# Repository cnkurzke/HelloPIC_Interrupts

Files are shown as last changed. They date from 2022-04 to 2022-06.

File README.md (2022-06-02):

# About

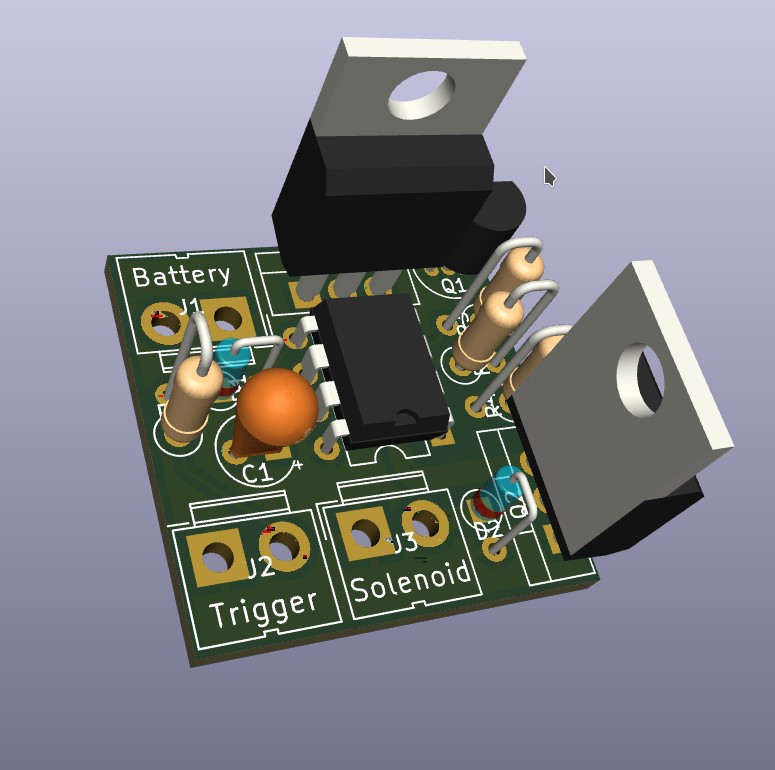
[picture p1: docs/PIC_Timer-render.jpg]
3D render PCB


This is part of my adventure of learning how to use PIC Microcontrollers in the real world.
If you want to learn more about what a PIC is, here are plenty of online resources. E.g. see here:

* https://en.wikipedia.org/wiki/PIC_microcontrollers
* https://www.microchip.com/en-us/products/microcontrollers-and-microprocessors
* https://pic-microcontroller.com/pic16f877-based-projects-pic-microcontroller-downloadable/

My intention is to document my learning journey, so others can hopefully find it useful on
their own research and learning path. I strongly encourage everyone who finds a mistake, 
be it an oversight or something out of date, *please file a bug, or even better, contribute a fix!*

## My Setup

I try to do this as cleaply as possible, so that it can be reproduced by everyone.

My primary workstation is a standard PC with Ubuntu (currently version 20.04), and I use the 
PicKit 3. If you intend to purchase a programmer, be aware that the PicKit 2 is no longer 
supported by the current (2022) generation of development tools.

As the software environmnet, I am not happy with the Microchip tools, but it is the quickest way to
get started.
In fact, I installed a Virtual Machine, and run the MPLab IDE inside the VM. But if you have a
more "traditional" operating system, you should be fine to run this on your standard computer.
Follow the steps here:
https://www.microchip.com/en-us/tools-resources/develop/mplab-x-ide

# What Does It Do

I started with a very simple problem. For a car I'm currently restoring, I needed something
to control the "Transmission Reverse Lock-Out". For a commercial device, look at 
https://shiftsst.com/tremec-6-speed-reverse-lockout-control-module.html

What's relevant for this level of detail:
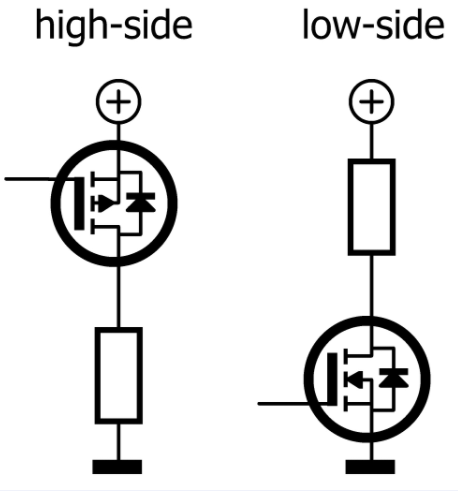
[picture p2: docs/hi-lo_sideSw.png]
Low-side vs. high-side
      

*  The goal is to drive an automotive grade 12 volt Solenoid which is wired to the car in a 
   "High-Side Switch" configuration.
   What this means:
   *  The module we build will have to be able to deliver high current, and it is an 
      "inductive load".
      Therefore I chose a beefy MOSFET to drive the signal to the transmission.
      
   *  The solenoid is permanently connected to "ground", and we have to close a switch to 12V to
      activate the solenoid and unlock the reverse gear. This means we have a 
      P-Channel MOSFET in "High Side Switching" configuration.
      For an example see here: https://www.elektormagazine.com/news/high-side-low-side-switching

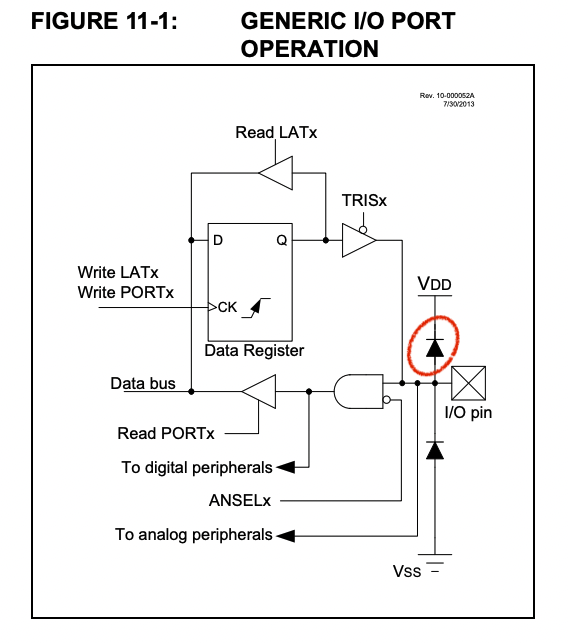
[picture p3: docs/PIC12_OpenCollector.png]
Open Collector with Clamping Diode
    * 
      The P-Channel MOSFET needs to be driven by a 12V Gate voltage, annd can unfortunately not
      be driven by the PIC output pin. Even though the Datasheet mentions that PIC outputs are
      able to work as "open Collector" - this is only thue for voltages within the operating
      voltage level. The circeled Diode in the diagram shows that the PIC has internal 
      clamping Diodes for protection.
      
*  The logic implemented by this device is to:
  *  Whenever the vehicle is turned on: Activate the solenoid for 30 seconds 
  *  When the driver pushes a trigger buttom: Activate the solenoid for 30 seconds 

This is a fairly simple timer circuit.

# Hardware Choices

After a bit of research, I decided the 8-pin PIC 12F1572 is more than capable.
It has 6 GPIOs, and holds 2KB memory.
See the datasheet here: https://www.microchip.com/en-us/product/PIC12F1572

For the MOSFET I decided to use the: https://www.sparkfun.com/datasheets/Components/General/FQP27P06.pdf
It can easily drive 20+ Amp, and most important, it has an integrated "fly back diode" to handle switching the inductive load.

Here's an early sketch of a circuit: 

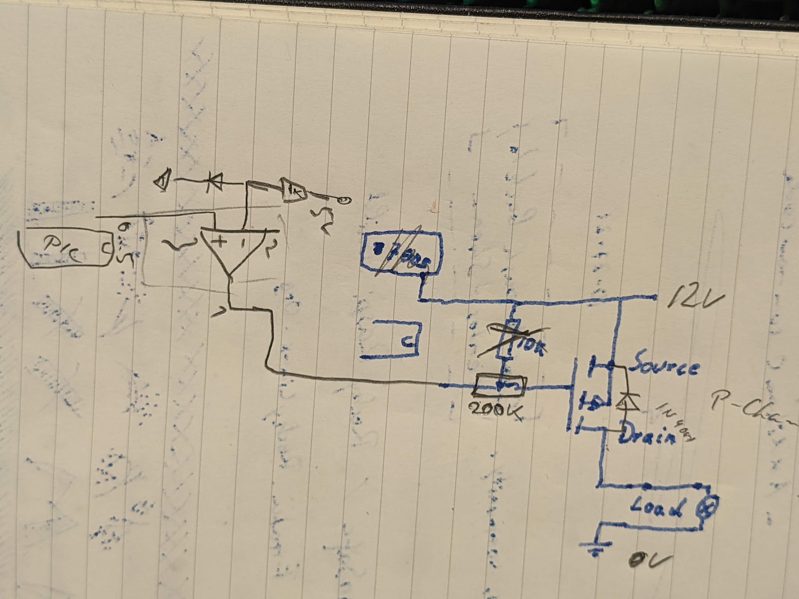
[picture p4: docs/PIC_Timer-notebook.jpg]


It became apparent rather quickly that the biggest challenge would be, how to drive the 12V MOSFET from the 5V PIC output.

## MOSFET Drriver

It turns out that the PIC output pins, even though they are "Open Collector" capable, they are protected by a diode, which prevents to pull-up to 12V.

I looked at various MOSFET Drivers, but they are really not needed, for the low (basically DC) switching  freqencies.
In this case, a simple NPN BJT in Open Collector mode is suficcient.

## Prototype

After a bit of breadboarding, I had the first version up and running rather quickly. 

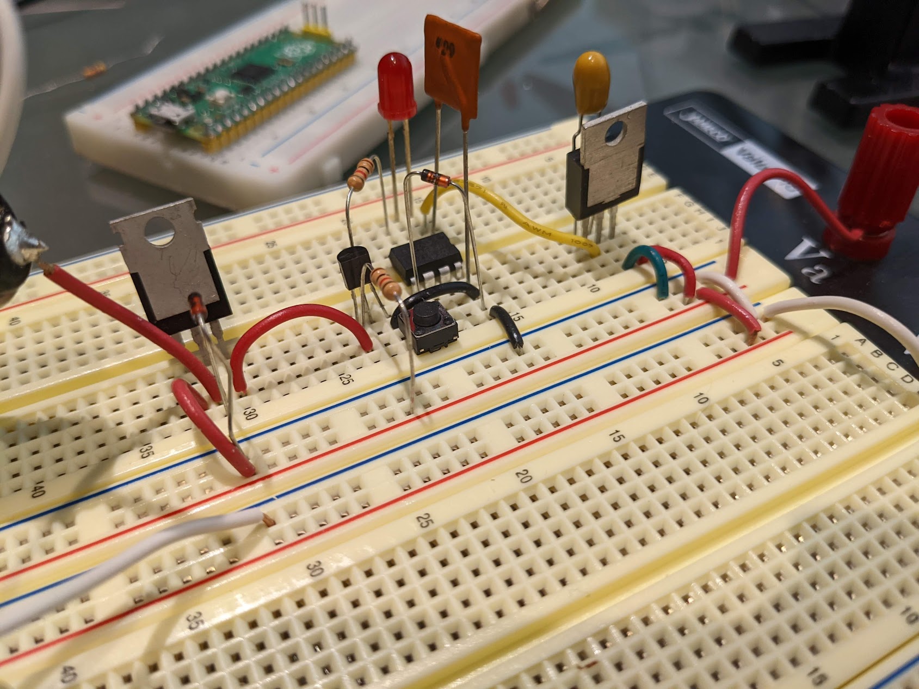
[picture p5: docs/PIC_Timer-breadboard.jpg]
Breadboard with components


# KiCAD Schematics

I decided to create "REAL" circuit boards. After a bit of research, the free software "KiCAD" cauught my interest. It's everything  I need, and way, way more!
See: https://www.kicad.org/

After some trial and error and watching tutorials like: https://www.youtube.com/watch?v=ia2n7P3Csac

I created this schematic:
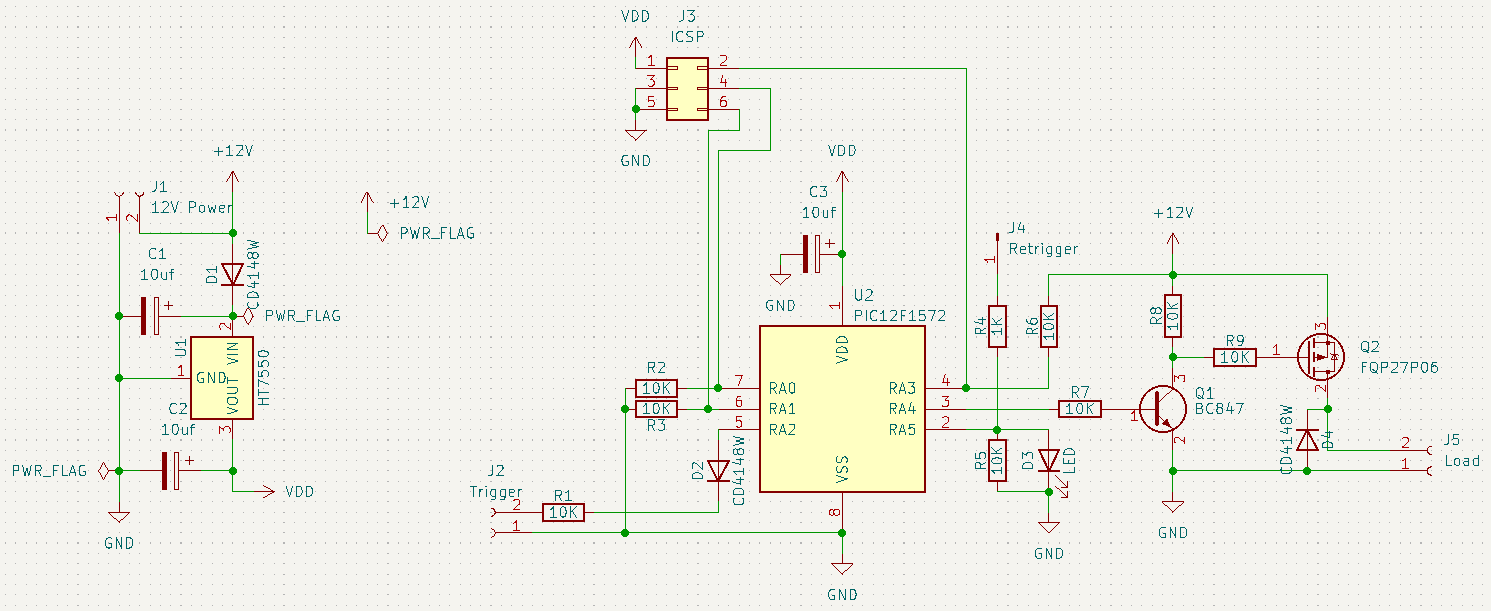
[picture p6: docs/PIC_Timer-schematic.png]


The source for this is here: https://github.com/cnkurzke/HelloPIC_Interrupts/tree/master/schematics

# PCB Layout

With the help of KiCAD, i turned this schematic into a circuit board, and Gerber files: 
https://github.com/cnkurzke/HelloPIC_Interrupts/tree/master/schematics/KiCAD_project/PIC_Timer/gerbers

The Gerber files describe the PCB and are used to manufacture the final boards:
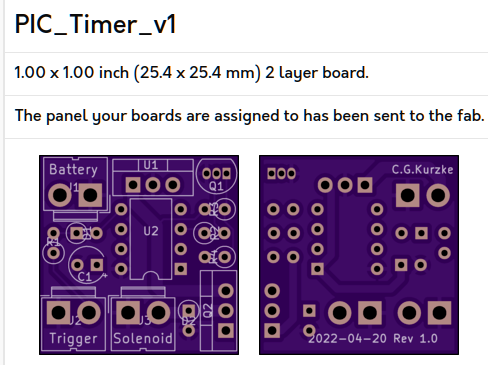
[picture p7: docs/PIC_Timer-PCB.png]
Printed Circuit Board


... stay tuned, the boards will arrive in 5 days

To be continued

# SOFTWARE 

## HelloPIC_Interrupts
Sample code for the PIC 12F1572 interrupt handling.

For a very basic introduction about Interrupts on PIC see:
https://picguides.com/beginner/interrupts.php

The Interrupt handler gets registered in main.c, with     
`IOCAF2_SetInterruptHandler(IOCAF2_CGK_InterruptHandler);`

The ISR (`IOCAF2_CGK_InterruptHandler()`) is called everytime the RA2 is pulled to LOW.

More in detail information about De-Bouncing Switches: 
http://www.ganssle.com/debouncing-pt2.htm

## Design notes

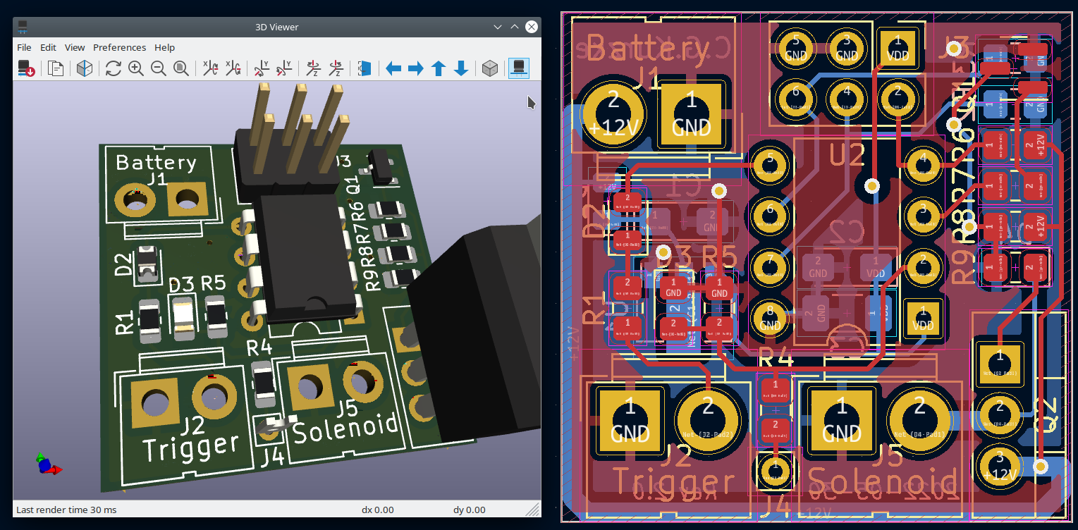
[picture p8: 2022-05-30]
docs/PIC_Timer-PCB-SMD-3D.png

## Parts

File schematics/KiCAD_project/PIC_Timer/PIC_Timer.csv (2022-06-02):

Source: | /home/cgk/MPLABXProjects/HelloInterrupt.X/schematics/KiCAD_project/PIC_Timer/PIC_Timer.kicad_sch
Date: | Mon 30 May 2022 12:20:11 AM PDT
Tool: | Eeschema 6.0.5-a6ca702e91~116~ubuntu20.04.1
Generator: | /usr/share/kicad/plugins/bom_csv_grouped_by_value_with_fp.py
Component Count: | 25
Ref | Qnty | Value | Cmp name | Footprint | Description | Vendor
C1, C2, | 2 | 10uf | C_Polarized | Capacitor_Tantalum_SMD:CP_EIA-3216-10_Kemet-I_Pad1.58x1.35mm_HandSolder | Polarized capacitor
C3, | 1 | 10uf | C_Polarized | Capacitor_SMD:C_1206_3216Metric_Pad1.33x1.80mm_HandSolder | Polarized capacitor
D1, D2, D4, | 3 | CD4148W | CD4148W | Diode_SMD:D_0805_2012Metric | 75V 0.15A Switching Diode, 0805
D3, | 1 | LED | LED | LED_SMD:LED_0805_2012Metric_Pad1.15x1.40mm_HandSolder | Light emitting diode
J1, | 1 | 12V Power | Conn_01x02_Female | Connector:JWT_A3963_1x02_P3.96mm_Vertical | Generic connector, single row, 01x02, script generated (kicad-library-utils/schlib/autogen/connector/)
J2, | 1 | Trigger | Conn_01x02_Female | Connector:JWT_A3963_1x02_P3.96mm_Vertical | Generic connector, single row, 01x02, script generated (kicad-library-utils/schlib/autogen/connector/)
J3, | 1 | ICSP | Conn_02x03_Odd_Even | Connector_PinHeader_2.54mm:PinHeader_2x03_P2.54mm_Vertical | Generic connector, double row, 02x03, odd/even pin numbering scheme (row 1 odd numbers, row 2 even numbers), script generated (kicad-library-utils/schlib/autogen/connector/)
J4, | 1 | Retrigger | Conn_01x01_Male | Connector_Pin:Pin_D0.7mm_L6.5mm_W1.8mm_FlatFork | Generic connector, single row, 01x01, script generated (kicad-library-utils/schlib/autogen/connector/)
J5, | 1 | Load | Conn_01x02_Female | Connector:JWT_A3963_1x02_P3.96mm_Vertical | Generic connector, single row, 01x02, script generated (kicad-library-utils/schlib/autogen/connector/)
Q1, | 1 | BC847 | BC847 | Package_TO_SOT_SMD:SOT-23 | 0.1A Ic, 45V Vce, NPN Transistor, SOT-23
Q2, | 1 | FQP27P06 | FQP27P06 | Package_TO_SOT_THT:TO-220-3_Vertical | -27A Id, -60V Vds, QFET P-Channel MOSFET, TO-220
R1, R2, R3, R5, R6, R7, R8, R9, | 8 | 10K | R | Resistor_SMD:R_0805_2012Metric_Pad1.20x1.40mm_HandSolder | Resistor
R4, | 1 | 1K | R | Resistor_SMD:R_0805_2012Metric_Pad1.20x1.40mm_HandSolder | Resistor
U1, | 1 | HT7550 | HT75xx-1-SOT89 | Package_TO_SOT_SMD:SOT-89-3 | 100mA Low Dropout Voltage Regulator, Fixed Output, SOT89
U2, | 1 | PIC12F1572 | PIC12F1501-IP | Package_DIP:DIP-8_W7.62mm | 1024W FLASH, 64B SRAM, PDIP8

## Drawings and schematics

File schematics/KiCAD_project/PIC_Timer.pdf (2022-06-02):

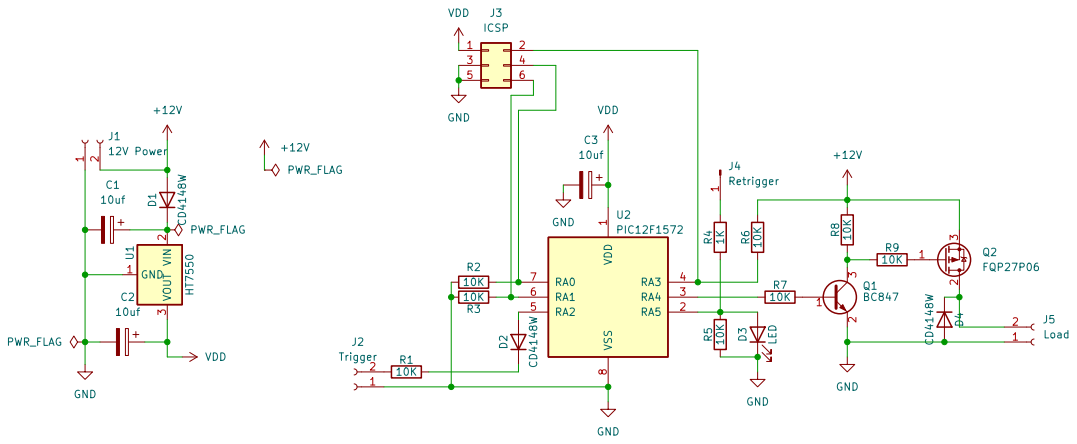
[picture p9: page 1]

Added retrigger and dedbug LED
Use SMD to accomodate better layout
File: PIC_Timer.kicad_sch Sheet: / Slipstream Systems, LLC

Id: 1/1 Title: Delay / Retrigger - Control Power MOSFET

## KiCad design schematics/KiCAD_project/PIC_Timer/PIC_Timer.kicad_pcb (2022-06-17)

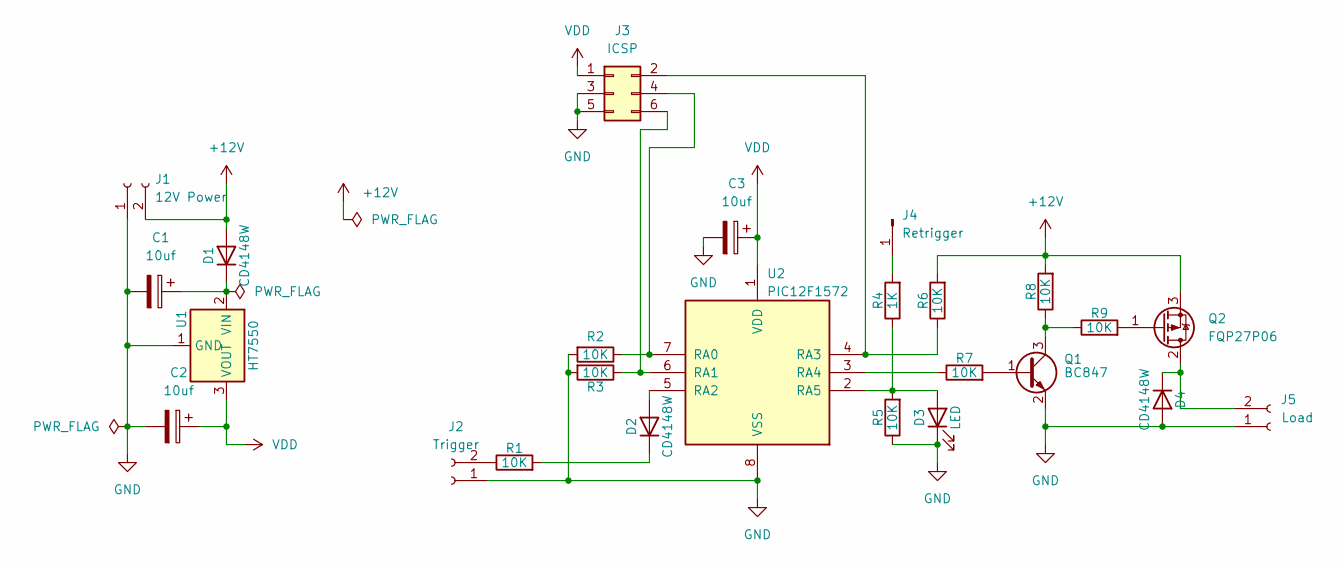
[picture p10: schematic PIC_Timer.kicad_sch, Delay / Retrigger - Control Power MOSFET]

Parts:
C1, C2: 10uf; CP_EIA-3216-10_Kemet-I_Pad1.58x1.35mm_HandSolder
C3: 10uf; C_1206_3216Metric_Pad1.33x1.80mm_HandSolder
D1, D2, D4: CD4148W; D_0805_2012Metric
D3: LED; LED_0805_2012Metric_Pad1.15x1.40mm_HandSolder
J1: 12V Power; JWT_A3963_1x02_P3.96mm_Vertical
J2: Trigger; JWT_A3963_1x02_P3.96mm_Vertical
J3: ICSP; PinHeader_2x03_P2.54mm_Vertical
J4: Retrigger; Pin_D0.7mm_L6.5mm_W1.8mm_FlatFork
J5: Load; JWT_A3963_1x02_P3.96mm_Vertical
Q1: BC847; SOT-23
Q2: FQP27P06; TO-220-3_Vertical
R1, R2, R3, R5, R6, R7, R8, R9: 10K; R_0805_2012Metric_Pad1.20x1.40mm_HandSolder
R4: 1K; R_0805_2012Metric_Pad1.20x1.40mm_HandSolder
U1: HT7550; SOT-89-3
U2: PIC12F1572; DIP-8_W7.62mm

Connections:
+12V: D1.2 (A), J1.2, Q2.3 (S), R6.2, R8.2
GND: C1.2, C2.2, C3.2, D3.1 (K), D4.2 (A), J1.1, J2.1, J3.3, J3.5, J5.1, Q1.2 (E), R2.2, R3.2, R5.1, U1.1 (GND), U2.8 (VSS)
unnamed: C1.1, D1.1 (K), U1.2 (VIN)
unnamed: D2.1 (K), R1.2
unnamed: D2.2 (A), U2.5 (RA2)
unnamed: D3.2 (A), R4.1, R5.2, U2.2 (RA5)
unnamed: D4.1 (K), J5.2, Q2.2 (D)
unnamed: J2.2, R1.1
unnamed: J3.2, R6.1, U2.4 (RA3)
unnamed: J3.4, R2.1, U2.7 (RA0)
unnamed: J3.6, R3.1, U2.6 (RA1)
unnamed: J4.1, R4.2
unnamed: Q1.1 (B), R7.2
unnamed: Q1.3 (C), R8.1, R9.1
unnamed: Q2.1 (G), R9.2
unnamed: R7.1, U2.3 (RA4)
VDD: C2.1, C3.1, J3.1, U1.3 (VOUT), U2.1 (VDD)

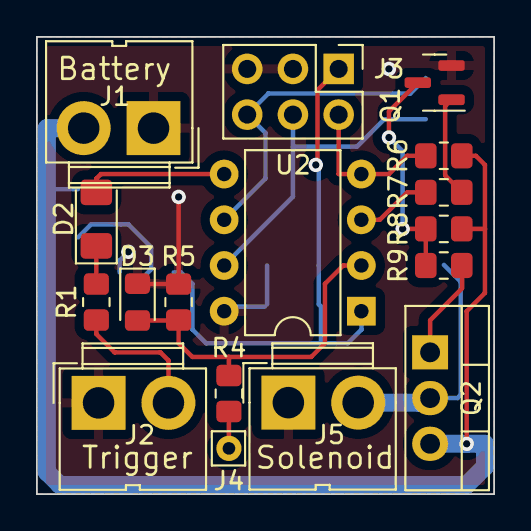
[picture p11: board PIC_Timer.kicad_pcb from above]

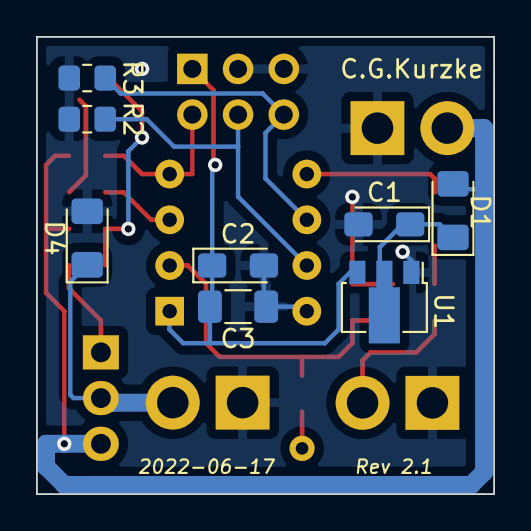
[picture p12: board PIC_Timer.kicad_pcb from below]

Board: 2 copper layers, 25.4 x 25.4 mm, 25 parts (8 on the bottom side), 17 nets.

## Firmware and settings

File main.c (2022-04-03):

/**
  Generated Main Source File

  Company:
    Microchip Technology Inc.

  File Name:
    main.c

  Summary:
    This is the main file generated using PIC10 / PIC12 / PIC16 / PIC18 MCUs

  Description:
    This header file provides implementations for driver APIs for all modules selected in the GUI.
    Generation Information :
        Product Revision  :  PIC10 / PIC12 / PIC16 / PIC18 MCUs - 1.81.7
        Device            :  PIC12F1572
        Driver Version    :  2.00
*/

/*
    (c) 2018 Microchip Technology Inc. and its subsidiaries. 
    
    Subject to your compliance with these terms, you may use Microchip software and any 
    derivatives exclusively with Microchip products. It is your responsibility to comply with third party 
    license terms applicable to your use of third party software (including open source software) that 
    may accompany Microchip software.
    
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
    IN NO EVENT WILL MICROCHIP BE LIABLE FOR ANY INDIRECT, SPECIAL, PUNITIVE, 
    INCIDENTAL OR CONSEQUENTIAL LOSS, DAMAGE, COST OR EXPENSE OF ANY KIND 
    WHATSOEVER RELATED TO THE SOFTWARE, HOWEVER CAUSED, EVEN IF MICROCHIP 
    HAS BEEN ADVISED OF THE POSSIBILITY OR THE DAMAGES ARE FORESEEABLE. TO 
    THE FULLEST EXTENT ALLOWED BY LAW, MICROCHIP'S TOTAL LIABILITY ON ALL 
    CLAIMS IN ANY WAY RELATED TO THIS SOFTWARE WILL NOT EXCEED THE AMOUNT 
    OF FEES, IF ANY, THAT YOU HAVE PAID DIRECTLY TO MICROCHIP FOR THIS 
    SOFTWARE.
*/

#include "mcc_generated_files/mcc.h"

/*
                         Main application
 */


#define LOCKOUT_TIME 10         // time in seconds
#define LOCKOUT_GRANULARITY 100 // granularity in millisec
volatile int32_t g_lockoutTimer = LOCKOUT_TIME * 1000 / LOCKOUT_GRANULARITY;

void IOCAF2_CGK_InterruptHandler(void){
    // IO_RA4_Toggle();
    g_lockoutTimer = LOCKOUT_TIME * 1000 / LOCKOUT_GRANULARITY;
}


void main(void)
{
    // initialize the device
    SYSTEM_Initialize();

    // When using interrupts, you need to set the Global and Peripheral Interrupt Enable bits
    // Use the following macros to:

    // Enable the Global Interrupts
    INTERRUPT_GlobalInterruptEnable();

    // Enable the Peripheral Interrupts
    INTERRUPT_PeripheralInterruptEnable();

    // Disable the Global Interrupts
    //INTERRUPT_GlobalInterruptDisable();

    // Disable the Peripheral Interrupts
    //INTERRUPT_PeripheralInterruptDisable();

    // register Interrupt Handler Function 
    IOCAF2_SetInterruptHandler(IOCAF2_CGK_InterruptHandler);
   
    IO_RA5_SetHigh();
    IO_RA4_SetHigh();
    
    while (1)
    {
        // Add your application code
        //IO_RA4_Toggle();
        IO_RA5_Toggle();
        
        if (g_lockoutTimer > 0) {
            g_lockoutTimer--;
            IO_RA4_SetHigh();
        } else {
            IO_RA4_SetLow();
        }
           
        
        __delay_ms(LOCKOUT_GRANULARITY);
        
    }
}
/**
 End of File
*/

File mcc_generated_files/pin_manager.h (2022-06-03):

/**
  @Generated Pin Manager Header File

  @Company:
    Microchip Technology Inc.

  @File Name:
    pin_manager.h

  @Summary:
    This is the Pin Manager file generated using PIC10 / PIC12 / PIC16 / PIC18 MCUs

  @Description
    This header file provides APIs for driver for .
    Generation Information :
        Product Revision  :  PIC10 / PIC12 / PIC16 / PIC18 MCUs - 1.81.7
        Device            :  PIC12F1572
        Driver Version    :  2.11
    The generated drivers are tested against the following:
        Compiler          :  XC8 2.31 and above
        MPLAB 	          :  MPLAB X 5.45	
*/

/*
    (c) 2018 Microchip Technology Inc. and its subsidiaries. 
    
    Subject to your compliance with these terms, you may use Microchip software and any 
    derivatives exclusively with Microchip products. It is your responsibility to comply with third party 
    license terms applicable to your use of third party software (including open source software) that 
    may accompany Microchip software.
    
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
    IN NO EVENT WILL MICROCHIP BE LIABLE FOR ANY INDIRECT, SPECIAL, PUNITIVE, 
    INCIDENTAL OR CONSEQUENTIAL LOSS, DAMAGE, COST OR EXPENSE OF ANY KIND 
    WHATSOEVER RELATED TO THE SOFTWARE, HOWEVER CAUSED, EVEN IF MICROCHIP 
    HAS BEEN ADVISED OF THE POSSIBILITY OR THE DAMAGES ARE FORESEEABLE. TO 
    THE FULLEST EXTENT ALLOWED BY LAW, MICROCHIP'S TOTAL LIABILITY ON ALL 
    CLAIMS IN ANY WAY RELATED TO THIS SOFTWARE WILL NOT EXCEED THE AMOUNT 
    OF FEES, IF ANY, THAT YOU HAVE PAID DIRECTLY TO MICROCHIP FOR THIS 
    SOFTWARE.
*/

#ifndef PIN_MANAGER_H
#define PIN_MANAGER_H

/**
  Section: Included Files
*/

#include <xc.h>

#define INPUT   1
#define OUTPUT  0

#define HIGH    1
#define LOW     0

#define ANALOG      1
#define DIGITAL     0

#define PULL_UP_ENABLED      1
#define PULL_UP_DISABLED     0

// get/set IO_RA0 aliases
#define IO_RA0_TRIS                 TRISAbits.TRISA0
#define IO_RA0_LAT                  LATAbits.LATA0
#define IO_RA0_PORT                 PORTAbits.RA0
#define IO_RA0_WPU                  WPUAbits.WPUA0
#define IO_RA0_OD                   ODCONAbits.ODA0
#define IO_RA0_ANS                  ANSELAbits.ANSA0
#define IO_RA0_SetHigh()            do { LATAbits.LATA0 = 1; } while(0)
#define IO_RA0_SetLow()             do { LATAbits.LATA0 = 0; } while(0)
#define IO_RA0_Toggle()             do { LATAbits.LATA0 = ~LATAbits.LATA0; } while(0)
#define IO_RA0_GetValue()           PORTAbits.RA0
#define IO_RA0_SetDigitalInput()    do { TRISAbits.TRISA0 = 1; } while(0)
#define IO_RA0_SetDigitalOutput()   do { TRISAbits.TRISA0 = 0; } while(0)
#define IO_RA0_SetPullup()          do { WPUAbits.WPUA0 = 1; } while(0)
#define IO_RA0_ResetPullup()        do { WPUAbits.WPUA0 = 0; } while(0)
#define IO_RA0_SetPushPull()        do { ODCONAbits.ODA0 = 0; } while(0)
#define IO_RA0_SetOpenDrain()       do { ODCONAbits.ODA0 = 1; } while(0)
#define IO_RA0_SetAnalogMode()      do { ANSELAbits.ANSA0 = 1; } while(0)
#define IO_RA0_SetDigitalMode()     do { ANSELAbits.ANSA0 = 0; } while(0)

// get/set IO_RA1 aliases
#define IO_RA1_TRIS                 TRISAbits.TRISA1
#define IO_RA1_LAT                  LATAbits.LATA1
#define IO_RA1_PORT                 PORTAbits.RA1
#define IO_RA1_WPU                  WPUAbits.WPUA1
#define IO_RA1_OD                   ODCONAbits.ODA1
#define IO_RA1_ANS                  ANSELAbits.ANSA1
#define IO_RA1_SetHigh()            do { LATAbits.LATA1 = 1; } while(0)
#define IO_RA1_SetLow()             do { LATAbits.LATA1 = 0; } while(0)
#define IO_RA1_Toggle()             do { LATAbits.LATA1 = ~LATAbits.LATA1; } while(0)
#define IO_RA1_GetValue()           PORTAbits.RA1
#define IO_RA1_SetDigitalInput()    do { TRISAbits.TRISA1 = 1; } while(0)
#define IO_RA1_SetDigitalOutput()   do { TRISAbits.TRISA1 = 0; } while(0)
#define IO_RA1_SetPullup()          do { WPUAbits.WPUA1 = 1; } while(0)
#define IO_RA1_ResetPullup()        do { WPUAbits.WPUA1 = 0; } while(0)
#define IO_RA1_SetPushPull()        do { ODCONAbits.ODA1 = 0; } while(0)
#define IO_RA1_SetOpenDrain()       do { ODCONAbits.ODA1 = 1; } while(0)
#define IO_RA1_SetAnalogMode()      do { ANSELAbits.ANSA1 = 1; } while(0)
#define IO_RA1_SetDigitalMode()     do { ANSELAbits.ANSA1 = 0; } while(0)

// get/set IO_RA2 aliases
#define IO_RA2_TRIS                 TRISAbits.TRISA2
#define IO_RA2_LAT                  LATAbits.LATA2
#define IO_RA2_PORT                 PORTAbits.RA2
#define IO_RA2_WPU                  WPUAbits.WPUA2
#define IO_RA2_OD                   ODCONAbits.ODA2
#define IO_RA2_ANS                  ANSELAbits.ANSA2
#define IO_RA2_SetHigh()            do { LATAbits.LATA2 = 1; } while(0)
#define IO_RA2_SetLow()             do { LATAbits.LATA2 = 0; } while(0)
#define IO_RA2_Toggle()             do { LATAbits.LATA2 = ~LATAbits.LATA2; } while(0)
#define IO_RA2_GetValue()           PORTAbits.RA2
#define IO_RA2_SetDigitalInput()    do { TRISAbits.TRISA2 = 1; } while(0)
#define IO_RA2_SetDigitalOutput()   do { TRISAbits.TRISA2 = 0; } while(0)
#define IO_RA2_SetPullup()          do { WPUAbits.WPUA2 = 1; } while(0)
#define IO_RA2_ResetPullup()        do { WPUAbits.WPUA2 = 0; } while(0)
#define IO_RA2_SetPushPull()        do { ODCONAbits.ODA2 = 0; } while(0)
#define IO_RA2_SetOpenDrain()       do { ODCONAbits.ODA2 = 1; } while(0)
#define IO_RA2_SetAnalogMode()      do { ANSELAbits.ANSA2 = 1; } while(0)
#define IO_RA2_SetDigitalMode()     do { ANSELAbits.ANSA2 = 0; } while(0)

// get/set IO_RA4 aliases
#define IO_RA4_TRIS                 TRISAbits.TRISA4
#define IO_RA4_LAT                  LATAbits.LATA4
#define IO_RA4_PORT                 PORTAbits.RA4
#define IO_RA4_WPU                  WPUAbits.WPUA4
#define IO_RA4_OD                   ODCONAbits.ODA4
#define IO_RA4_ANS                  ANSELAbits.ANSA4
#define IO_RA4_SetHigh()            do { LATAbits.LATA4 = 1; } while(0)
#define IO_RA4_SetLow()             do { LATAbits.LATA4 = 0; } while(0)
#define IO_RA4_Toggle()             do { LATAbits.LATA4 = ~LATAbits.LATA4; } while(0)
#define IO_RA4_GetValue()           PORTAbits.RA4
#define IO_RA4_SetDigitalInput()    do { TRISAbits.TRISA4 = 1; } while(0)
#define IO_RA4_SetDigitalOutput()   do { TRISAbits.TRISA4 = 0; } while(0)
#define IO_RA4_SetPullup()          do { WPUAbits.WPUA4 = 1; } while(0)
#define IO_RA4_ResetPullup()        do { WPUAbits.WPUA4 = 0; } while(0)
#define IO_RA4_SetPushPull()        do { ODCONAbits.ODA4 = 0; } while(0)
#define IO_RA4_SetOpenDrain()       do { ODCONAbits.ODA4 = 1; } while(0)
#define IO_RA4_SetAnalogMode()      do { ANSELAbits.ANSA4 = 1; } while(0)
#define IO_RA4_SetDigitalMode()     do { ANSELAbits.ANSA4 = 0; } while(0)
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

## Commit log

2022-04-03 Reversed the output RA4 to accommodate open-collector transistor driver for MOSFET
    [main.c]
2022-04-03 Added KiKAD Schematics files
    [PIC_Timer.kicad_pcb, PIC_Timer.kicad_sch]
2022-04-11 Created KiCAD schematics
    [PIC_Timer.kicad_pcb, PIC_Timer.kicad_sch]
2022-04-13 placed and rendered in 1 sqare inch
    [PIC_Timer.kicad_pcb, PIC_Timer.kicad_sch]
2022-04-16 Rev 1.0 Gerber Files
    [PIC_Timer.kicad_pcb]
2022-04-22 Files as sent to PCB maker
    [PIC_Timer-B_Cu.gbr, PIC_Timer-B_Mask.gbr, PIC_Timer-B_Silkscreen.gbr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]
2022-04-29 clean up, deleted stale PDFs & Gerbers
    [PIC_Timer-B_Cu.gbr, PIC_Timer-B_Mask.gbr, PIC_Timer-B_Silkscreen.gbr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]
2022-05-26 minor fixes
    [PIC_Timer.kicad_sch]
2022-05-27 converted to SMD
    [PIC_Timer.kicad_pcb, PIC_Timer.kicad_sch]
2022-05-30 Rev 2.0 of SMD PCB
    [PIC_Timer.kicad_pcb, PIC_Timer.kicad_sch]
2022-05-30 update BOM, PDFs
2022-06-02 added BOM and updated Schmatics PDF
    [PIC_Timer.csv]
2022-06-03 Configured RA0 and RA1 as INPUT, hardwired to GND to improve ESD resistance
2022-06-17 changed Diodes from 0805 to 1206 to accomodate the 1n4148 SMD
    [PIC_Timer.kicad_pcb]
